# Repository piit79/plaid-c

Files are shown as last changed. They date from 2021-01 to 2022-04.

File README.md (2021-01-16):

Plaid-C
=================

plaid

The 4x12 ortholinear keyboard kit made by through hole components only.

This is an updated version modified to use USB-C instead of Mini USB by piit79.

Atmega328p with VUSB on [QMK firmware](https://github.com/qmk/qmk_firmware).

[Build guide and bom is here](./doc)
[ビルドガイドとパーツリストはこちら](./doc)

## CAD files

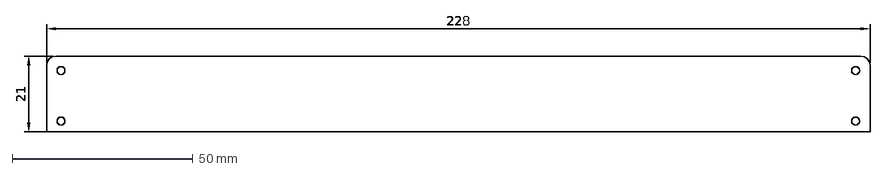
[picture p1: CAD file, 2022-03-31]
pcb/plaid-cover.dxf
228
21

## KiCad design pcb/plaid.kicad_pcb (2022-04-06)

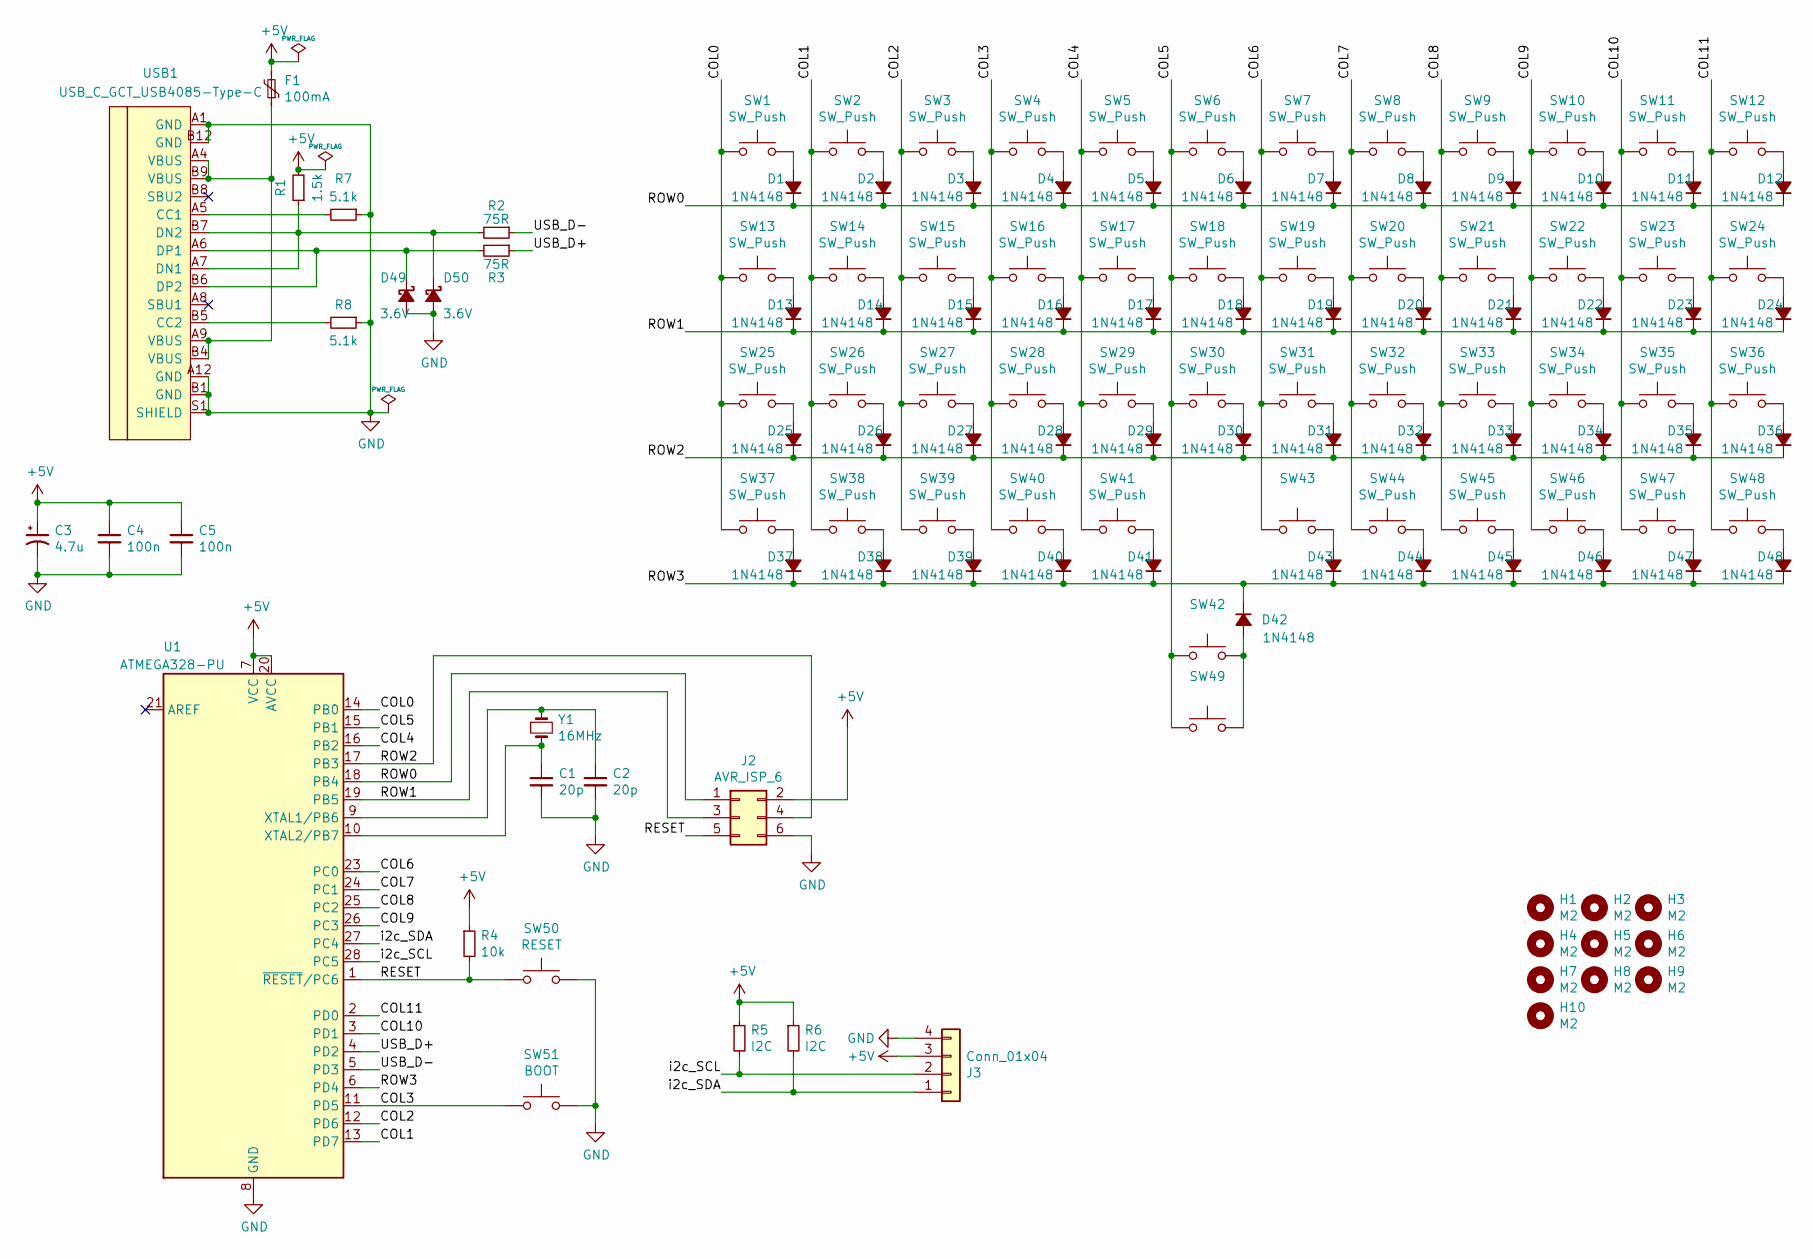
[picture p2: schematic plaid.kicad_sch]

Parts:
C1, C2: 20p; C_Disc_D3.0mm_W1.6mm_P2.50mm
C3: 4.7u; CP_Radial_D4.0mm_P1.50mm
C4, C5: 100n; C_Disc_D4.3mm_W1.9mm_P5.00mm
D1, D2, D3, D4, D5, D6, D7, D8, D9, D10, D11, D12, D13, D14, D15, D16, D17, D18, D19, D20, D21, D22, D23, D24, D25, D26, D27, D28, D29, D30, D31, D32, D33, D34, D35, D36, D37, D38, D39, D40, D41, D42, D43, D44, D45, D46, D47, D48: 1N4148; D_DO-35_SOD27_P5.08mm_Horizontal
D49, D50: 3.6V; D_DO-35_SOD27_P5.08mm_Horizontal
F1: 100mA; polyfuse_5.1mm
H1, H2, H3, H4, H5, H6, H7, H8, H9, H10: M2; MountingHole_2.2mm_M2_Pad
J2: AVR_ISP_6; Pin_Header_Straight_2x03_Pitch2.54mm
J3: Conn_01x04; OLED_v2
R1: 1.5k; R_Axial_DIN0204_L3.6mm_D1.6mm_P5.08mm_Horizontal
R2, R3: 75R; R_Axial_DIN0204_L3.6mm_D1.6mm_P5.08mm_Horizontal
R4: 10k; R_Axial_DIN0204_L3.6mm_D1.6mm_P5.08mm_Horizontal
R5, R6: I2C; R_Axial_DIN0204_L3.6mm_D1.6mm_P5.08mm_Horizontal
R7, R8: 5.1k; R_Axial_DIN0204_L3.6mm_D1.6mm_P5.08mm_Horizontal
SW1, SW2, SW3, SW4, SW5, SW6, SW7, SW8, SW9, SW10, SW11, SW12, SW13, SW14, SW15, SW16, SW17, SW18, SW19, SW20, SW21, SW22, SW23, SW24, SW25, SW26, SW27, SW28, SW29, SW30, SW31, SW32, SW33, SW34, SW35, SW36, SW37, SW38, SW39, SW40, SW41, SW44, SW45, SW46, SW47, SW48: SW_Push; MX-Choc-1U-NoLED
SW42, SW43, SW49: (no value)
SW50: RESET; SW_PUSH_6mm
SW51: BOOT; SW_PUSH_6mm
U1: ATMEGA328-PU; DIP-28_W7.62mm
USB1: USB_C_GCT_USB4085-Type-C; USB_C_GCT_USB4085-offset-pads
Y1: 16MHz; Crystal_HC49-4H_Vertical

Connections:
+5V: C3.1, C4.1, C5.1, F1.2, J2.2, J3.3, R1.2, R4.1, R5.1, R6.1, U1.7 (VCC), U1.20 (AVCC)
/COL0: SW1.2, SW13.2, SW25.2, SW37.2, U1.14 (PB0)
/COL1: SW2.2, SW14.2, SW26.2, SW38.2, U1.13 (PD7)
/COL2: SW3.2, SW15.2, SW27.2, SW39.2, U1.12 (PD6)
/COL3: SW4.2, SW16.2, SW28.2, SW40.2, SW51.1, U1.11 (PD5)
/COL4: SW5.2, SW17.2, SW29.2, SW41.2, U1.16 (PB2)
/COL5: SW6.2, SW18.2, SW30.2, SW42.2, SW49.2, U1.15 (PB1)
/COL6: SW7.2, SW19.2, SW31.2, SW43.2, U1.23 (PC0)
/COL7: SW8.2, SW20.2, SW32.2, SW44.2, U1.24 (PC1)
/COL8: SW9.2, SW21.2, SW33.2, SW45.2, U1.25 (PC2)
/COL9: SW10.2, SW22.2, SW34.2, SW46.2, U1.26 (PC3)
/COL10: SW11.2, SW23.2, SW35.2, SW47.2, U1.3 (PD1)
/COL11: SW12.2, SW24.2, SW36.2, SW48.2, U1.2 (PD0)
/RESET: J2.5, R4.2, SW50.1, U1.1 (~RESET/PC6)
/ROW0: D1.1 (K), D2.1 (K), D3.1 (K), D4.1 (K), D5.1 (K), D6.1 (K), D7.1 (K), D8.1 (K), D9.1 (K), D10.1 (K), D11.1 (K), D12.1 (K), J2.1, U1.18 (PB4)
/ROW1: D13.1 (K), D14.1 (K), D15.1 (K), D16.1 (K), D17.1 (K), D18.1 (K), D19.1 (K), D20.1 (K), D21.1 (K), D22.1 (K), D23.1 (K), D24.1 (K), J2.3, U1.19 (PB5)
/ROW2: D25.1 (K), D26.1 (K), D27.1 (K), D28.1 (K), D29.1 (K), D30.1 (K), D31.1 (K), D32.1 (K), D33.1 (K), D34.1 (K), D35.1 (K), D36.1 (K), J2.4, U1.17 (PB3)
/ROW3: D37.1 (K), D38.1 (K), D39.1 (K), D40.1 (K), D41.1 (K), D42.1 (K), D43.1 (K), D44.1 (K), D45.1 (K), D46.1 (K), D47.1 (K), D48.1 (K), U1.6 (PD4)
/USB_D+: R2.1, U1.4 (PD2)
/USB_D-: R3.1, U1.5 (PD3)
/i2c_SCL: J3.2, R5.2, U1.28 (PC5)
/i2c_SDA: J3.1, R6.2, U1.27 (PC4)
GND: C1.2, C2.2, C3.2, C4.2, C5.2, D49.2 (A), D50.2 (A), J2.6, J3.4, R7.1, R8.1, SW50.2, SW51.2, U1.8 (GND), U1.22 (GND), USB1.A1 (GND), USB1.A12 (GND), USB1.B1 (GND), USB1.B12 (GND), USB1.S1 (SHIELD)
unnamed: C1.1, U1.10 (XTAL2/PB7), Y1.2
unnamed: C2.1, U1.9 (XTAL1/PB6), Y1.1
unnamed: D1.2 (A), SW1.1
unnamed: D2.2 (A), SW2.1
unnamed: D3.2 (A), SW3.1
unnamed: D4.2 (A), SW4.1
unnamed: D5.2 (A), SW5.1
unnamed: D6.2 (A), SW6.1
unnamed: D7.2 (A), SW7.1
unnamed: D8.2 (A), SW8.1
unnamed: D9.2 (A), SW9.1
unnamed: D10.2 (A), SW10.1
unnamed: D11.2 (A), SW11.1
unnamed: D12.2 (A), SW12.1
unnamed: D13.2 (A), SW13.1
unnamed: D14.2 (A), SW14.1
unnamed: D15.2 (A), SW15.1
unnamed: D16.2 (A), SW16.1
unnamed: D17.2 (A), SW17.1
unnamed: D18.2 (A), SW18.1
unnamed: D19.2 (A), SW19.1
unnamed: D20.2 (A), SW20.1
unnamed: D21.2 (A), SW21.1
unnamed: D22.2 (A), SW22.1
unnamed: D23.2 (A), SW23.1
unnamed: D24.2 (A), SW24.1
unnamed: D25.2 (A), SW25.1
unnamed: D26.2 (A), SW26.1
unnamed: D27.2 (A), SW27.1
unnamed: D28.2 (A), SW28.1
unnamed: D29.2 (A), SW29.1
unnamed: D30.2 (A), SW30.1
unnamed: D31.2 (A), SW31.1
unnamed: D32.2 (A), SW32.1
unnamed: D33.2 (A), SW33.1
unnamed: D34.2 (A), SW34.1
unnamed: D35.2 (A), SW35.1
unnamed: D36.2 (A), SW36.1
unnamed: D37.2 (A), SW37.1
unnamed: D38.2 (A), SW38.1
unnamed: D39.2 (A), SW39.1
unnamed: D40.2 (A), SW40.1
unnamed: D41.2 (A), SW41.1
unnamed: D42.2 (A), SW42.1, SW49.1
unnamed: D43.2 (A), SW43.1
unnamed: D44.2 (A), SW44.1
unnamed: D45.2 (A), SW45.1
unnamed: D46.2 (A), SW46.1
unnamed: D47.2 (A), SW47.1
unnamed: D48.2 (A), SW48.1
unnamed: D49.1 (K), R2.2, USB1.A6 (DP1), USB1.B6 (DP2)
unnamed: D50.1 (K), R1.1, R3.2, USB1.A7 (DN1), USB1.B7 (DN2)
unnamed: F1.1, USB1.A4 (VBUS), USB1.A9 (VBUS), USB1.B4 (VBUS), USB1.B9 (VBUS)
unnamed: R7.2, USB1.A5 (CC1)
unnamed: R8.2, USB1.B5 (CC2)

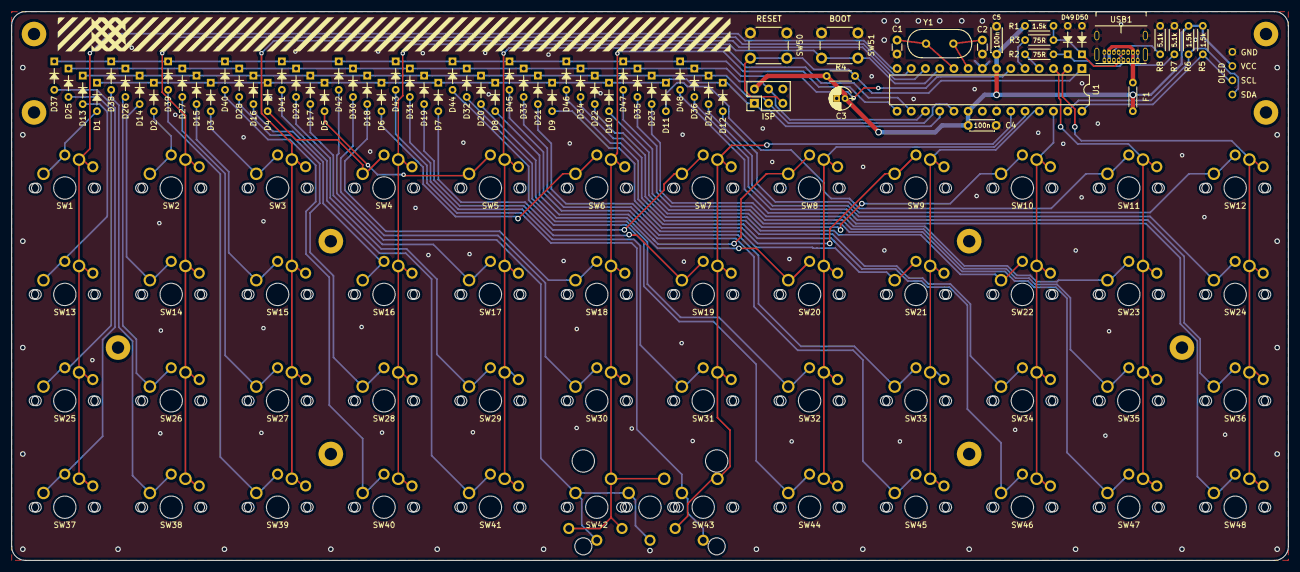
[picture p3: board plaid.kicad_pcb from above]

Board: 2 copper layers, 228.0 x 98.0 mm, 130 parts (0 on the bottom side), 78 nets.

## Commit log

2021-01-15 Replace Mini USB connector with USB-C
    [plaid.kicad_pcb, plaid.sch]
2021-01-16 Add gerber zip files
2021-02-03 Add switch plate files (MIT and grid layouts)
    [plaid_plate_grid.kicad_pcb, plaid_plate_mit.kicad_pcb]
2021-02-03 Add plate gerber zip
2022-03-31 Move elyt away from OLED; use USB-C with offset pads; switch to KiCad 6 filenames
    [plaid-cover.dxf, plaid.kicad_sch, plaid.sch]
2022-03-31 Add KiCad library SMKJP_kicad_components as a submodule
2022-03-31 Add 42. Keebs KiCad library as a submodule
2022-03-31 Add support for Kailh Choc switches
    [plaid-B_Cu.gbr, plaid-B_Mask.gbr, plaid-B_Silkscreen.gbr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]
2022-04-06 Add universal MIT/grid plate
    [plaid_plate_mit_grid-B_Cu.gbr, plaid_plate_mit_grid-B_Mask.gbr, plaid_plate_mit_grid-B_Silkscreen.gbr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]
2022-04-06 Fix spacebar(s) - use "opposing" footprints
    [plaid-B_Cu.gbr, plaid-B_Mask.gbr, plaid-B_Silkscreen.gbr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]

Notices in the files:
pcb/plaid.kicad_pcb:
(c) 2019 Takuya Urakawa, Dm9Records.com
